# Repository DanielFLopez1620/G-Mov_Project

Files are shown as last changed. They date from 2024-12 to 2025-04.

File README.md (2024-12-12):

# G-Mov Project

G-Mov comes from Guardian of Movement. It is a project that aims to integrates robotics in the care of elderly people by combining ROS 2 and IoT for a dashbaord visualization over a local network. By adding a modular kit composed of a pi camera, a servo and a accelerometer to ROS 2 robots with the objective to track people fall detection by implementing Computer Vision (CV) and also using the movement of the robot.

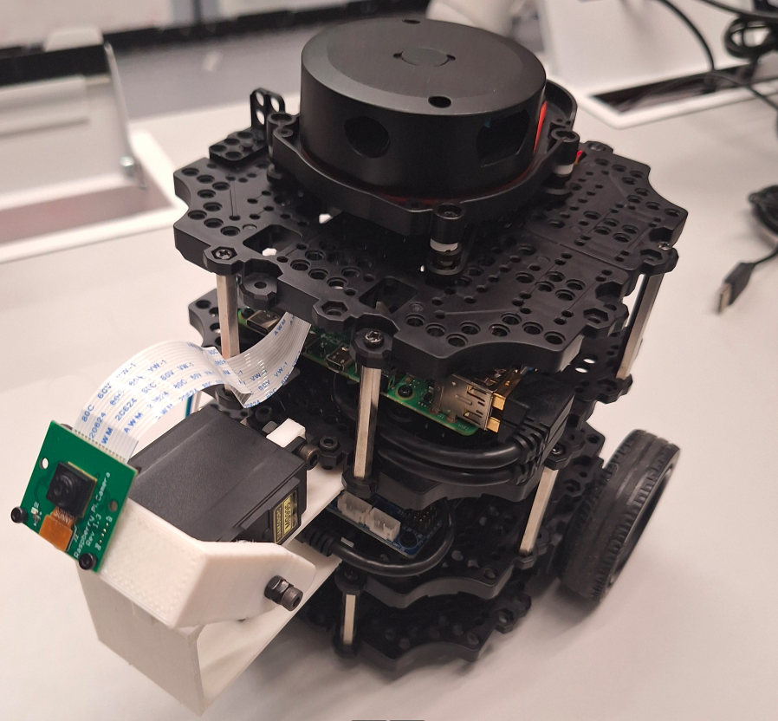
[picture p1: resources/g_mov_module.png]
g_mov_module


For this first version, we have used the [Turtlebot3 Burger](https://emanual.robotis.com/docs/en/platform/turtlebot3/overview/). You can find the demo videos below:

- People tracking:

g_mov_people_tracking

- Fall detection:

g_mov_fall_detection

- Dashboard servo control:

g_mov_servo_control

These videos were recorded at normal speed. If you want to check the original video, you can go to the [G-Mov Phase 3 | Youtube Video](https://youtu.be/IMeLtWwy5p4)

## Technical Information:

This project combines ROS 2 nodes with communication over MQTT by using [Mosquitto](https://mosquitto.org/) and [Thingsboard](https://thingsboard.io/) to generate an interaction between the ROS 2 ecosystem, scripts for CV and communication, a website and a dashboard.

As a note, for now the CV and image processing is made inside the raspberry due to lossy transport of images.

The structure of the project is shown below:

### Packages:

- **[g_mov_base:](/g_mov_base/README.md)** Package with the source code for running the sensors and actuators, and communicating the info over ROS 2 workflow and also with MQTT for Mosquitto, ThingsSpeak and Thingsboard. It also contains the hardware elements and assembly considerations.
- **[g_mov_description:](/g_mov_description/README.md)** Directory that contains the CAD files made in [FreeCad](https://www.freecad.org/) to allow modifications and the .stl files for printing them.
- **[g_mov_cam:](/g_mov_cam/README.md)** Beta package that has experiments for image compression and image transport as it fails and doesn't allow for using the image in another remote ROS 2 system.
- **[g_mov_local_mqtts_notes:](/g_mov_local_mqtts_notes/README.md)** Contains the proper explanation on how to set up Mosquitto broker (base and TLS) and Thingsboard (base installation) for the communication over a local network that must be accesible to the robot and at least another PC.
- **[g_mov_msgs:](/g_mov_msgs/README.md)** Pacakge that contains custom messages, in this case, oriented for the servo pose with a stamped time.
- **[g_mov_opencv_py:](/g_mov_opencv_py/README.md)** Package that incoporates [OpenCV](https://opencv.org/) and [MediaPipe](https://ai.google.dev/edge/mediapipe/solutions/guide) for image processing and CV to detect people fall detection.
- **[g_mov_webpage](/g_mov_webpage/README.md):** Directory that contains the information of the Website that was made with [Flask](https://flask.palletsprojects.com/en/stable/), HTML, CSS and [Bootstrap](https://getbootstrap.com/).

## Limitations:

For now, the project works only with Turtlebot3 and runs with Ubuntu 22.04 for ROS 2 Humble Distro. This was a project made for the IoT Course for the Pontificia Universidad Javeriana, so another limitation was the time to work on the project.

Some additional constraints and limitations to consider are:

- Although it is a IoT project, it just works over a local network as the authors didn't integrate a network host or domain for the webpage due to time limitations.
- The tracking of the person, just works on open spaces where there are not walls where the person could hide and the robot is only able to move in spaces that doesn't have stairs or important height changes. It is possible to detect some parts of the body if the person is behind a partial obstacle but this may affect the tracking.
- Most of the processing is running on the raspberry, so according to the model, it may go slower.

## Future work:

Next semester, according to the develop of the career of the members, have the mission to accomplish one or more of the next items:

* Make a modular design of the kit to allow integration with other robots, for example, [DiffDan](https://github.com/DanielFLopez1620/diff_robot_dan_ros)
* Integrate Docker for easy deployment / installation of the Dashboard and connections.
* Explore integration with SLAM / Nav 2 packages for a more powerful people tracking algorithm in closed spaces.
* Study alternatives for image transport

## About the Authors:

This project was originally made by:

- Daniel Felipe López Escobar : [DanielFLopez1620](https://github.com/DanielFLopez1620)

- Guillermo Aguilera [Best-Gagil](https://github.com/Best-Gagil)

- Cristhian Jose Narvaez. [Criss19](https://github.com/Crisss19)

This project was made by members of the [IEEE RAS Pontificia Unversidad Javeriana Student Chapter](https://linktr.ee/rasjaverianaieee). We would like to thank for the unconditional support and the loan of Turtlebot3 to the directives and members of the Student Chapter.

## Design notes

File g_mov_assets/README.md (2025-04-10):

# g_mov_asssets

In this directory, you can find the cad files and the assembly for the **G-Mov Project** which was made using [FreeCad](https://www.freecad.org/) 1.0.0.

The directory [cad_files](/g_mov_assets/cad_files/) includes all the source files in the .FCStd extension.

The directory [iges_files](/g_mov_assets/iges_files/) includes exported .iges files inc ase you want to make modifications to the project with a different CAD software.

Feel free to modify and generate new versions of this project and share it with us and the community!

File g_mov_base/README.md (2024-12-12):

# g_mov_base

Package oriented to integrate the sensors and actuators of the project into the ROS 2 workflow and enable communication with MQTT for Thingspeak, Thingsboard and Mosquitto.

## Connections and physical set up:

The G-Mov model aims to work with ROS 2 robots that work over a Raspberry Pi 3, 4 or 5 that has the camera port available and allow additional GPIO connections. The elements are:

- **ServoMotor MG996r or MG995:** Actuator that will reorientate the camera for better tracking of the person.

- **MPU6050 Module:** Accelerometer/Gyroscope integration for getting feedback on the robot status.

- **Raspberry Pi Cam:** In this case, the Module V2, which is easy to integrate with the Raspberry Pi and aims for the CV application related with the fall detection tracking system.

The connection for this is presented in the image below (Raspberry Pi 4 case):

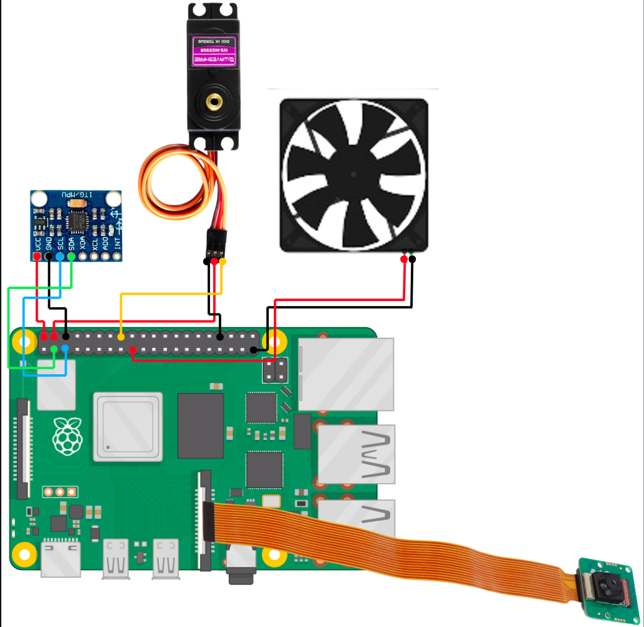
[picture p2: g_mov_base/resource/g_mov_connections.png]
g_mov_connection


In terms of the connection the MPU6050 is connected to the I2C ports of the RPi4, the servo is attached to the GPIO 16 and the cmaera is connected to the proper camera port. All the power connections (5V and GND) are made following the pinout of the RPi (the options presented were added considering ease during installation.) In the case of the Turtlebot3, as it gets power from the RPi 5V port, you can change the MPU6050 to a 3.3 V, move the servo port to the first 5V port and search for another GND to connect the MPU650.

You can 3D print the [g_mov_base_support](/g_mov_description/mesh_files/base_gmov-Body.stl) piece and install all the components there with the appropiate M3 screw for the Turtlebot3 burger model, where you can add the camera in the front or in the back of the robot according to your needs (just keep in mind to change the cmd_vel commands orientation and direction according to the position on the robot, by default, the camara is added at the back of the robot).

## Nodes:

The nodes you can find for this package are presented below:

- **[accel_publisher.py](/g_mov_base/g_mov_base/accel_publisher.py)** : Node that read the I2C connections of the MPU6050, convert it to the provert acceleration and orientation, and publish it to the ROS 2 ecosystem in form of a *AccelStamped* msg.
- **[mosquitto_accel_sub.py](/g_mov_base/g_mov_base/mosquitto_accel_sub.py)** : ROS 2 subscriber that interprates the *AccelStamped* info provided and publish it to the specified Mosquitto broker.
- **[mosquito_fall_sub.py](/g_mov_base/g_mov_base/mosquitto_fall_sub.py)** : ROS 2 subscriber that reads the boolean flag for fall detection and publsih it to the specified Mosquitto broker.
- **[mosquito_servo_sub.py](/g_mov_base/g_mov_base/mosquitto_servo_sub.py)** : ROS 2 subscriber that reads the servo angle and publish it to the specified Mosquitto broker.
- **[servo_subscriber.py](/g_mov_base/g_mov_base/servo_subscriber.py)** : ROS 2 subscriber that folllows the info of a custom *ServoPoseStamped*, interpret it and command the position by using the GPIO ports to the servo.
- **[thingsboatd_accel_sub.py](/g_mov_base/g_mov_base/thingsboard_accel_sub.py)** : ROS 2 subscriber that read the *AccelStamped* info provided and publish it to the specified Thingsboard broker in order to visualize it in a dashboard.
- **[thingsboatd_fall_sub.py](/g_mov_base/g_mov_base/thingsboard_fall_sub.py)** : ROS 2 subscriber that read a boolean flag for fall detection and publish it to the specified Thingsboard broker in order to visualize it in a dashboard.
- **[thingsboatd_servo_sub.py](/g_mov_base/g_mov_base/thingsboard_servo_sub.py)** : ROS 2 subscriber that read the custom *ServoPoseStamped* info provided and publish it to the specified Thingsboard broker in order to visualize it in a dashboard.
- **[thingsboatd_servo_pub.py](/g_mov_base/g_mov_base/thingsboard_servo_sub.py)** : ROS 2 publisher that considers a specified pose in the Thingsboard dashboard and publish the corresponding *ServoPoseStamped* msg.
- **[thingspeak_accel_sub.py](/g_mov_base/g_mov_base/thingspeak_accel_sub.py) : ROS 2 subscriber that aimed to test MQTT connection with Thingspeak from Matlab and explore the usage of this solution during early stages of the project.

## Launch files:

To ease the process of running the sensor and communication nodes, the next launch files were created: 

- **[thingsboard_nodes.launch.py](/g_mov_base/launch/thingsboard_nodes.launch.py)** : Launch file that starts all the Thingsboard nodes for MQTT communication with the dashboard.

- **[sensors_bringup.launch.py](/g_mov_base/launch/sensors_bringup.launch.py)** : Launch files that starts the MPU6050, camera and servo to publish/subscribe in the ROS 2 ecosystem.

- **[mosquitto_nodes.launch.py](/g_mov_base/launch/mosquitto_nodes.launch.py)** : Launch file that initialize the Mosquitto ndoes for MQTT connections with the provided Mosquitto broker.

- **[g_mov_bringup.launch.py](/g_mov_base/launch/g_mov_bringup.launch.py):** Launch files that includes the sensors bringup and thingsboard launch for running the version 1.0 of the *G-Mov Project*.

## Execution:

Currently, the focus on the project is the Thingsboard's Dashboard intregration and the tracking/fall detection module running on the robot.

Before running the robot, make sure the PC hosting the Thingsboard Dashboard and the Thingsboard broker is running. After that you can proceed:

1. Make sure you have cloned the repository:

~~~bash
cd ~/ros2_ws/src
git clone https://github.com/DanielFLopez1620/G-Mov_Project.git
~~~

2. Ensure that all dependenices are available:

~~~bash
pip3 install mpu6050-raspberrypi 
pip3 install rpi-gpio
pip3 install paho-mqtt
pip3 install ssl
pip3 install DateTime
pip install opencv-python
pip install mediapipe
cd ~/ros2_ws
rosdep install --from-paths src --ignore-src --rosdistro humble -y
~~~

3. Ensure that you submitted the proper user/password, hosts and broker credentials before compiling and launching your nodes. This applies for the Mosquitto nodes with the corresponding Mosquitto Broker configuration and the Thingsboard Broker / Database configurations. 

NOTE: If you haven't started your Mosquitto or Thingsboard Services, check [g_mov_local_mqtts_notes](/g_mov_local_mqtts_notes/README.md) for more information.

4. Build the packages

~~~bash
cd ~/ros2_ws
colcon build --packages-select g_mov_msgs g_mov_opencv_py g_mov_base
~~~

5. Run the launch:

~~~bash
source ~/ros2_ws/install/setup.bash
ros2 launch g_mov_base g_mov_bringup.launch.py
~~~

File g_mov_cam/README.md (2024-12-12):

# g_mov_cam

This was a beta repostiroy to test about camera image transport in search for improvements due to heavy lost when using tandard image msgs from ROS 2.

## Nodes:

Here is presented the list of nodes available:

- [custom_image_transport.cpp](/g_mov_cam/src/custom_image_transport.cpp) : Node oriented to explore image transport with the *image_transport* msg by reading the camera with OpenCV.

## Execution:

1. Make sure you have cloned the repository:

~~~bash
cd ~/ros2_ws/src
git clone https://github.com/DanielFLopez1620/G-Mov_Project.git
~~~

2. Connect camera and check permissions, also validate number of device

~~~bash
v4l2-ctl --list-devices

# For example:
# Microsoft® LifeCam HD-3000: Mi (usb-0000:00:14.0-5):
#         /dev/video0
#         /dev/video1
#         /dev/media0
# Where the camera ID should be 0 or 1
~~~

3. Compile and run

~~~bash
cd ~/ros2_ws
colcon build --packages-select g_mov_cam
source ~/ros2_ws/install/setup.bash
ros2 run g_mov_cam custom_image_transport 0 # Or your camera device number
~~~

4. Check image transport

~~~bash
ros2 topic echo /raw_image/compressed
~~~

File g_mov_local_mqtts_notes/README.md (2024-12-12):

# Notes about MQTT with Mosquitto/Thingsboard

This file aims to keep constancy of the steps made when setting up Mosquitto/Thingsboard broker in a local network with or without TLS/SSL for the IoT communication. For additional information refer to the links provided.

## Thingsboard MQTT and Dashboard set up:

For this project, it was used the Thingsboard Community Edition for Ubuntu. The instruction installations are provided in the next link: [Installing Thingsboard CE on Ubuntu Server](https://thingsboard.io/docs/user-guide/install/ubuntu/). However, some modifications were made to the installation:

- PostgresSQL was selected as the ThingsBoard database.

- In the steps were the IP 127.0.0.1 was selected (localhost), it was replaced with the IP of the machine in the local network desired for the application. It was also achieved by adding a custom host to the */etc/hosts* file (Check below in the Mosquitto section for more information), for example in the step:

~~~bash
# psql -U postgres -d postgres -h 127.0.0.1 -W
psql -U postgres -d postgres -h <machine_ip> -W
~~~

- In the thingboard file, the *localhost* was replaced with the machine ip or hostname:

~~~conf
export DATABASE_TS_TYPE=sql
# export SPRING_DATASOURCE_URL=jdbc:postgresql://localhost:5432/thingsboard
export SPRING_DATASOURCE_URL=jdbc:postgresql://<machine_ip>:5432/thingsboard
export SPRING_DATASOURCE_USERNAME=postgres
export SPRING_DATASOURCE_PASSWORD=PUT_YOUR_POSTGRESQL_PASSWORD_HERE
export SQL_POSTGRES_TS_KV_PARTITIONING=MONTHS
~~~

- When asking about the queue service, *In Memory* was selected.

- For checking the installation (after waiting 2 minutes for the restartup) use the machine ip, isntaed of localhost, to connect to the Dashboard online. It should also work with other devices over the network, just make sure that no firewall isn't blocking the connection:

~~~link
http://<maiche_ip>:8080/
~~~

## Thinsboard MQTT with TLS

Although it was implemented at this point of the project, you can find more information on:

- [MQTT over TLS | Thingsboard IO](https://thingsboard.io/docs/user-guide/mqtt-over-ssl/)

## MQTT with TLS on local network with IP setup

After some days of experimentation, reading about Mosquitto Broker, exploring Paho Python Library and having existencial crisis with the keys for TLS by using OpenSSL. I want to include here a brief guide on how to set up the everything in order to have your MQTT broker with TLS for experiments in your local network without having to buy a online service for this if you are not sure if the implementation will work.

### Steps for configuring the keys on your PC

The PC in our case will act as our MQTT broker, for this consider the next steps:

1. Install all the required dependencies

~~~bash
# Mosquito dependencies
sudo apt install mosquitto mosquitto-client

# SSL/TLS dependencies

# Python required
pip3 install paho-mqtt
~~~
https://thingsboard.io/docs/user-guide/install/ubuntu/
2. Create a Certificate Authority Key (CA) key

~~~bash
sudo openssl genpkey -algorithm RSA -out /etc/mosquitto/ca_certicates/ca.key
~~~

3. Create a self-signed CA certificate, make sure to add a **CN** name like "LocalCA" or "test" or related:

~~~bash
sudo openssl req -new -x509 -days 365 -key /etc/mosquitto/ca_certificate/ca.key -out /etc/mosquitto/certs/ca.crt
~~~

4. Create folder for server certificates:

~~~bash
sudo mkdir -p /etc/mosquitto/certs
~~~

5. Generate a server key

~~~bash
sudo openssl genpkey -algorithm RSA -out /etc/mosquitto/certs/server.key
~~~

6. Create a certificate signing request (CSR), make sure to add in the **CN** field the IP adress or hostname or FQDN of your server (your PC). Also do not use the same info for the company or city field, as if they are the same, the verification of the keys can be omitted, which can lead to future errors.

~~~bash
sudo openssl req -new -key /etc/mosquitto/certs/server.key -out /etc/mosquitto/certs/server.csr
~~~

7. Sign the server certificate using the CA certificate:

~~~bash
sudo openssl x509 -req -in /etc/mosquitto/certs/server.csr -CA /etc/mosquitto/ca_certificates/ca.crt -CAkey /etc/mosquitto/ca_certificates/ca.key -CAcreateserial -out /etc/mosquitto/certs/server.crt -days 365
~~~

8. Configure permissions and ownership

~~~bash
sudo chmod 600 /etc/mosquitto/certs/server.key
sudo chmod 644 /etc/mosquitto/certs/server.crt
sudo chmod 644 /etc/mosquitto/certs/ca.crt

sudo chown mosquitto:mosquitto /etc/mosquitto/certs/server.crt

sudo chown mosquitto:mosquitto /etc/mosquitto/certs/server.key

sudo chown mosquitto:mosquitto /etc/mosquitto/ca_certificates/ca.crt
~~~

9. Update mosquitto configuration, open with your editor (by having sudo access) the mosquitto.conf file:

~~~bash
sudo nano /etc/mosquitto/mosquitto.conf
~~~

Then edit it to consider the next:

~~~bash
pid_file /run/mosquitto/mosquitto.pid

# persistence true
# persistence_location /var/lib/mosquitto/

log_type all
log_dest file /var/log/mosquitto/mosquitto.log

# include_dir /etc/mosquitto/conf.d

listener 8883
protocol mqtt

cafile /etc/mosquitto/ca_certificates/ca.crt
keyfile /etc/mosquitto/certs/server.key
certfile /etc/mosquitto/certs/server.crt

tls_version tlsv1.2

# Allow the next only for test, it is recommended to set user and password)
allow_anonymous true
~~~

10. Kill previous instances of mosquitto to prevent issues

~~~bash
sudo systemctl stop mosquitto
sudo killall mosquitto
~~~

11. Restart mosquitto

~~~bash
sudo systemctl start mosquitto
~~~

12. Test that everything is going right, by publishing and subscribing on different terminals

~~~bash
# Terminal 1
mosquitto_sub -h <hostname/ip> -t "test/topic" --cafile /etc/mosquitto/ca_certificates/ca.crt -p 8883
# Terminal 2
mosquitto_pub -h <hostname/ip> -t "test/topic" -m "Hello World" --cafile /etc/mosquitto/ca_certificates/ca.crt -p 8883
~~~

13. You can now run a Python code with Paho to test the publishing and subscribing, in this case if you are running from local, you should set insecure tls to avoid certain validations of paho that may block the connection.

~~~python
import paho.mqtt.client as mqtt
import ssl

broker = "<broker/hostname/ip>"  # Your PC's IP address (broker)
port = 8883  # Port for TLS/SSL

# Define topic
topic = "test/topic"

client_id = "mqtt_pub_client"

ca_cert = "/etc/mosquitto/ca_certificates/ca.crt"  # CA certificate (on Raspberry Pi)

def on_connect(client, userdata, flags, rc, properties):
    if rc == 0:
        print("Connected to broker successfully")
    else:
        print(f"Failed to connect, return code {rc}")

def on_publish(client, userdata, mid, rc, properties):
    print(f"Message published with mid: {mid}")

client = mqtt.Client(mqtt.CallbackAPIVersion.VERSION2, client_id=client_id)

client.tls_set(ca_certs=ca_cert,
               tls_version=ssl.PROTOCOL_TLSv1_2)
client.tls_insecure_set(True)

client.on_connect = on_connectFor Mosquitto issues
client.on_publish = on_publish

client.connect(broker, port)

client.loop_start()

message = "Hello, MQTT with TLS!"
result = client.publish(topic, message)

result.wait_for_publish()

client.loop_stop()
client.disconnect()

print("Disconnected from broker")
~~~

### Additional configurations for user and password

To prevent anonymous connections, you can set up a user and a password, for this you can follow the next steps:

1. Set up the user and password within the proper file with the command below, make sure to remember the password linked to the username

~~~bash
sudo mosquitto_passwd  -c /etc/mosquitto/passwd <username>
~~~

2. Modify your mosquitto.conf file in order to block anonymous connections and ask for user/password by checking a given file:

~~~bash
sudo nano /etc/mosquitto/mosquitto.conf
~~~

~~~bash
allow_anonymous false
password_file /etc/mosquitto/passwd
~~~

3. Test with a publication and a subscription by passing the proper username and password, along with the mosquitto_pub and mosquitto_sub command

~~~bash
# Terminal 1
mosquitto_sub -h 1<hostname/ip> -t "test/topic" --cafile /etc/mosquitto/certs/ca.crt -p 8883 -u <your_username> -P <your_password>

# Terminal 2
mosquitto_pub -h <hostname/ip> -t "test/topic" -m "Hello MQTT over TLS" --cafile /etc/mosquitto/certs/ca.crt -p 8883 -u <your_username> -P <your_password>
~~~

4. In the case you want to test with python, after the mqtt.Client connection, you should set the password and user:

~~~Python
client.username_pw_set("<user>", "<password>")
~~~

### Setting up raspberry pi

1. Make sure you have installed mosquitto on the Raspberry Pi

~~~bash
# Raspberry Terminal
sudo apt install mosquitto mosquitto-clients
~~~

2. You will need to pass the Certificate Authority to the pi, you can use:

~~~bash
# PC terminal
scp /etc/mosquitto/ca_certificates/ca.crt <pi_user>@<pi_ip>:/home/<pi_user>/
~~~

3. Move the **ca.crt** file to the proper location:

~~~bash
# Raspberry terminal
sudo cp ca.crt /etc/mosquitto/ca_certificates/
~~~

4. Test that everything is going OK with **mosquitto_pub** and **mosquitto_sub**

~~~bash
# Terminal 1
mosquitto_sub -h 1<hostname/ip> -t "test/topic" --cafile /etc/mosquitto/certs/ca.crt -p 8883 -u <your_username> -P <your_password>

# Terminal 2
mosquitto_pub -h <hostname/ip> -t "test/topic" -m "Hello MQTT over TLS" --cafile /etc/mosquitto/certs/ca.crt -p 8883 -u <your_username> -P <your_password>

~~~

5. You can now test with Paho in Python, by running the file [localhost_usps_tls.py](/g_mov_local_mqtts_notes/localhost_usps_tls.py)

But you should still need to use the **tls_insecure_set**. That is why we need to configure a hostname that will be covered in the next title.

## MQTT with TLS on local network with hostname setup

### MQTT set up for PC with hostname

1. In your local PC add a new host with the IP of your broker, in this case, your own IP adress.

~~~bash
sudo nano /etc/hosts
~~~

~~~bash
# By default, systemd-resolved or libnss-myhostname will resolve
# localhost and the system hostname if they're not specified here.
127.0.0.1       localhost
::1             localhost

# Add the next host for example, replace x with your IP
192.168.x.x   mqtt.local
~~~

2. Install avahi to resolve the hostname using mDNS:

~~~bash
sudo apt update
sudo apt install avahi-daemon
~~~

3. Enable and start the service

~~~bash
sudo systemctl start avahi-daemon
sudo systemctl enable avahi-daemon
~~~

4. Make sure that the hostname is connected 

~~~bash
ping mqtt.local
~~~

5. After this, you will need to generate new keys, you can generate them with a new name so you can use the previous one, in case you want to have the last configuration as a backup. Follow the next steps to configure the keys again.

6. Create a Certificate Authority Key (CA) key

~~~
sudo openssl genpkey -algorithm RSA -out ca_certificates/ca_host.key
~~~

7. Create a self-signed CA certificate, make sure to add a **CN** name like "LocalCA" or "test" or related:

~~~bash
sudo openssl req -new -x509 -days 365 -key ca_certificates/ca_host.key -out ca_certificates/ca_host.crt
~~~

8. Generate a server key

~~~bash
sudo openssl genpkey -algorithm RSA -out /etc/mosquitto/certs/server_host.key
~~~

9. Create a certificate signing request (CSR), make sure to add in the **CN** field the IP adress or hostname or FQDN of your server (your PC). Also do not use the same info for the company or city field, as if they are the same, the verification of the keys can be omitted, which can lead to future errors.

~~~bash
sudo openssl req -new -key /etc/mosquitto/certs/server_host.key -out /etc/mosquitto/certs/server_host.csr
~~~

10. Sign the server certificate using the CA certificate:

~~~bash
sudo openssl x509 -req -in /etc/mosquitto/certs/server_host.csr -CA /etc/mosquitto/ca_certificates/ca_host.crt -CAkey /etc/mosquitto/ca_certificates/ca_host.key -CAcreateserial -out /etc/mosquitto/certs/server_host.crt -days 365
~~~

11. Edit the mosquitto configuration

~~~bash
sudo nano /etc/mosquitto/mosquitto.conf
~~~

~~~bash
# A full description of the configuration file is at
# /usr/share/doc/mosquitto/examples/mosquitto.conf.example

pid_file /run/mosquitto/mosquitto.pid

log_type all
log_dest file /var/log/mosquitto/mosquitto.log

listener 8883 0.0.0.0
protocol mqtt

cafile /etc/mosquitto/ca_certificates/ca_host.crt
keyfile /etc/mosquitto/certs/server_host.key
certfile /etc/mosquitto/certs/server_host.crt 

tls_version tlsv1.2

allow_anonymous false
require_certificate false

password_file /etc/mosquitto/passwd
~~~

12. Restart mosquito services

~~~
sudo systemctl restart mosquitto
~~~

### MQTT set up for raspberry with hostname

1. In your local PC add a new host with the IP of your broker, in this case, your own IP adress.

~~~bash
sudo nano /etc/hosts
~~~

~~~bash
# By default, systemd-resolved or libnss-myhostname will resolve
# localhost and the system hostname if they're not specified here.
127.0.0.1       localhost
::1             localhost

# Add the next host for example, replace x with your IP
192.168.x.x   mqtt.local
~~~

2. Install avahi to resolve the hostname using DNS:

~~~bash
sudo apt update
sudo apt install avahi-daemon
~~~

3. Enable and start the service

~~~bash
sudo systemctl start avahi-daemon
sudo systemctl enable avahi-daemon
~~~

4. Make sure that the hostname is connected 

~~~bash
ping mqtt.local
~~~

## Troubleshooting:

- Make sure your host IP is unique, for example, if you have others IP set up like for NGrok, ZeroTier, Docker. It is better to disable them to prevent issues. For example, you can use in the case of Docker:

~~~
sudo ip link set docker<id> down
~~~

- If you are not sure about the IP or hostname you set up, it is better to add new keys.

- Remember, do not use the same city, location, company and unit info for CA and server keys, as it will lead to ignore a validation of the keys. Of just one character change, it will be enough

- Keep in mind that Thingsboard service may take 2 minutes to restart if you made some changes to the Thignsboard config or yaml file, this also applies for start up. In case, the startup doesn't apply the proper IP configuration, you should restart postgres and thingsboard services:

~~~bash
sudo systemctl restart postgres # It can also be postgres.service
sudo systemctl restart thingsboard.service
~~~

## Sources and References

- [Mosquitto MQTT Broker SSL Configuration Using Own Certificates | Steves Internet Guide](http://www.steves-internet-guide.com/mosquitto-tls/)

- [Creating and Using Client Certificates with MQTT and Mosquitto | Steves Internet Guide](http://www.steves-internet-guide.com/creating-and-using-client-certificates-with-mqtt-and-mosquitto/)

- [Mosquitto MQTT Broker SSL Configuration Using Own Certificates | Steves Internet Guide](http://www.steves-internet-guide.com/mosquitto-tls/)

- [paho-mqtt 2.1.0 | Pypi.org](https://pypi.org/project/paho-mqtt/#tls-set)

- [Paho Mqtt Python | Github by eclipse](https://github.com/eclipse/paho.mqtt.python)

- [Mosquitto.conf Man Page | Eclipse foundation & Mosquitt.org](https://mosquitto.org/man/mosquitto-conf-5.html)

- [Mosquitto Simple Config Example | Github by timWaizenegger](https://mosquitto.org/man/mosquitto-conf-5.html)

- [Migration Guide for Paho](https://eclipse.dev/paho/files/paho.mqtt.python/html/migrations.html)

- [Mosquitto_sub output format options | AsciiCinema by Raylight](https://asciinema.org/a/82233)

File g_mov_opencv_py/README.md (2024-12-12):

# G_MOV_OPENCV_PY

This package is oriented to integrate pose detection and face recognition in order to create a fall detection program.

The implementations provided here are based on the codes of [fall_detection_DL by barkhaarorra and MahiPajuja @ Github](https://github.com/barkhaaroraa/fall_detection_DL) that where adapted to work on a ROS 2 package and modified in order to run better in a Raspberry Pi 4.

## Installation

### Raspberry PI (Ubuntu 22.04):

Supposing you have python 3.10 (or higher) installed, have a ROS 2 Humble installation and you have cloned this  repository, follow the next steps:

1. Update and upgrade your system:

~~~bash
sudo apt update && sudo apt upgrade
~~~

2. Install Python dependencies and requiered libraries

~~~bash
sudo apt install python3-pip python3-dev libatlas-base-dev libhdf5-dev libjpeg-dev libpng-dev libtiff-dev libjasper-dev libv4l-dev libxvidcore-dev libx264-dev libdc1394-22-dev libgstreamer-plugins-base1.0-dev libgstreamer1.0-dev
~~~

3. Install dlib (required for face_recogniton)

~~~bash
pip3 install dlib
~~~

4. Install computer vision packages

~~~bash
pip3 install opencv-python
pip3 install mediapipe
pip3 install face_recogntion
~~~

5. Run the module example to make sure everythin is fine:

~~~bash
cd /path/to/repo/g_mov_opencv_py/g_mov_opencv_py # Replace with the proper path
python3 modules_demo.py
~~~

### PC (Ubuntu 22.04)

1. Update and upgrade your system:

~~~bash
sudo apt update && sudo apt upgrade
~~~

2. Install computer vision packages

~~~bash
pip3 install opencv-python
pip3 install mediapipe
pip3 install face_recogntion
~~~

3. Run the module example to make sure everythin is fine:

~~~bash
cd /path/to/repo/g_mov_opencv_py/g_mov_opencv_py # Replace with the proper path
python3 modules_demo.py
~~~

## Running the nodes:

1. Do not forget to go to your workspace and build the package

~~~bash
cd /path/to/ros2_ws # Replace with the proper path
colcon build --packages-select g_mov_opencv_py # To build this package only
source install/setup.bash
~~~

2. Run the node:

~~~bash
ros2 run g_mov_opencv_py fall_detect_img_raw_gui.py 
~~~

Refer to [g_mov_base](/g_mov_base/README.md) package in order to check full installation, dependencies and main launch execution.

## Troubleshooting:

- Do not forget to give the proper access to the camera

~~~bash
sudo chmod 666 /dev/video<num_of_camera>
~~~

- Sometimes when downloading multiple computer vision apps, matplotlib can install several times with different version. If you receive warnings related with matplotlib, uninstall and then reinstall it:

~~~bash
pip3 uninstall matplotlib
pip3 install matplotlib
~~~

- Be careful wiht the versions you install of OpenCV and Mediapipe, as they must be compatible. Otherwise, the codes won't work.

## Recommended resources:

- The system has a delay of a little more thant two seconds when running on a Raspeberry Pi 4, then it should be interesting to make tests with OpenCV by using C++ as suggests [StereoPi](https://stereopi.com/blog/opencv-comparing-speed-c-and-python-code-raspberry-pi-stereo-vision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,to%20be%20better%20at%20this) that demostrated it has a better time response for video capture.
- This project uses OpenCV Python, do not forget checking the [documentation](https://docs.opencv.org/3.4/d2/d75/namespacecv.html) if the comments aren't clear.
- This project uses MediaPipe, do not forget checking the [documentation](https://ai.google.dev/edge/mediapipe/solutions/guide) if the comments aren't clear

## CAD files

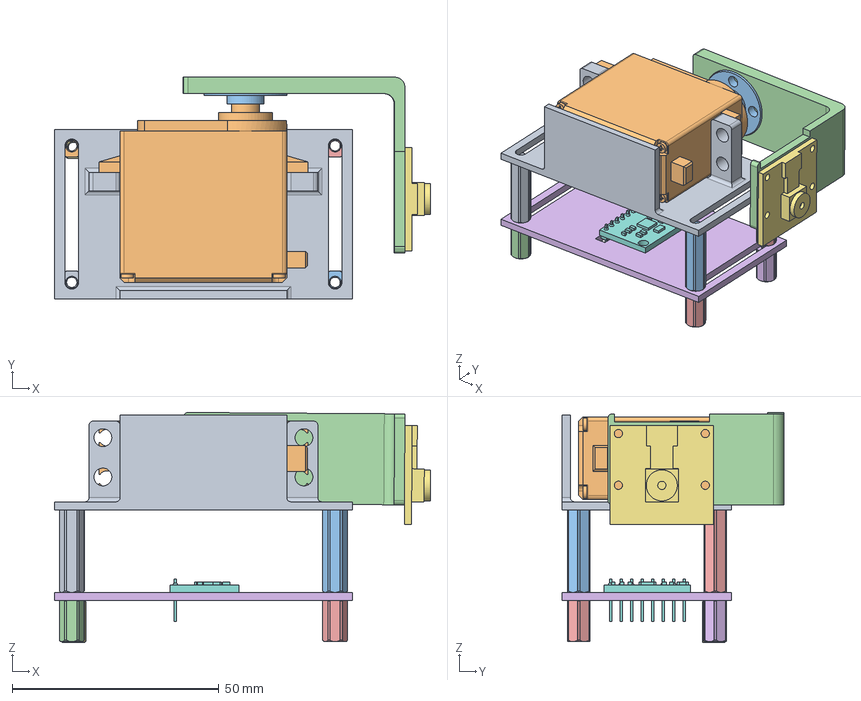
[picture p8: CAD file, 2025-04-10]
g_mov_assets/cad_files/g_mov_assembly.FCStd
90.9 x 53.6 x 55.6 mm
servo_base_001
servo_mg99_001
servo_connection_001
picam_support_001
hex_spacer_20mm_001
acccel_base_001
picam_001
accel_gy_mpu_001
hex_spacer_20mm_002
hex_spacer_20mm_003
hex_spacer_20mm_004
hex_spacer_10mm_001
hex_spacer_10mm_002
hex_spacer_10mm_003
hex_spacer_10mm_004

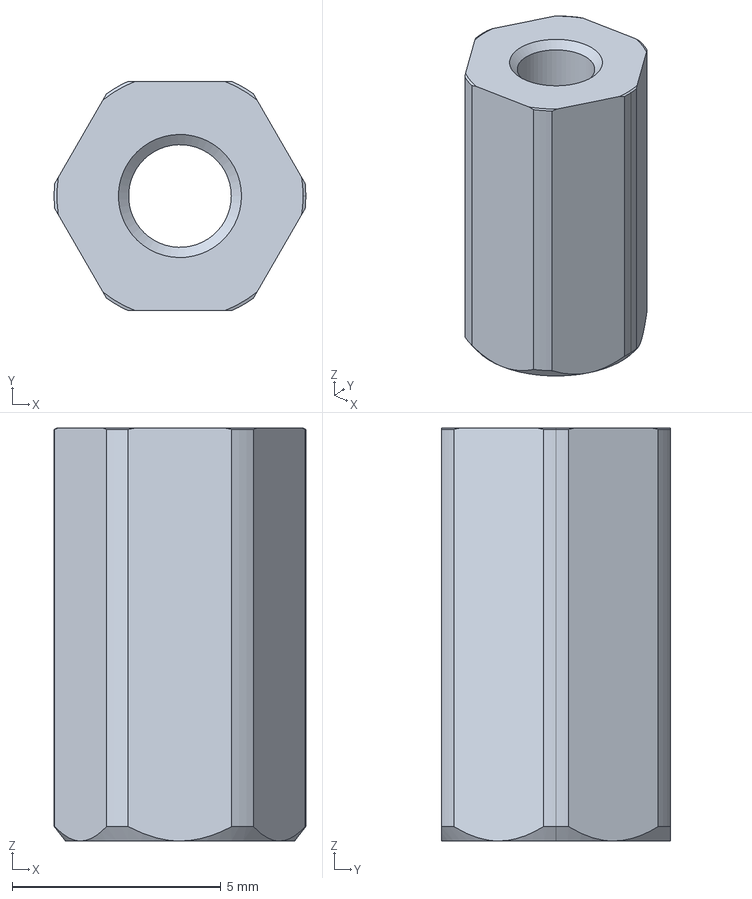
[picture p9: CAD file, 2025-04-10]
g_mov_assets/cad_files/hex_spacer_10mm.FCStd
6.03 x 5.50 x 9.90 mm

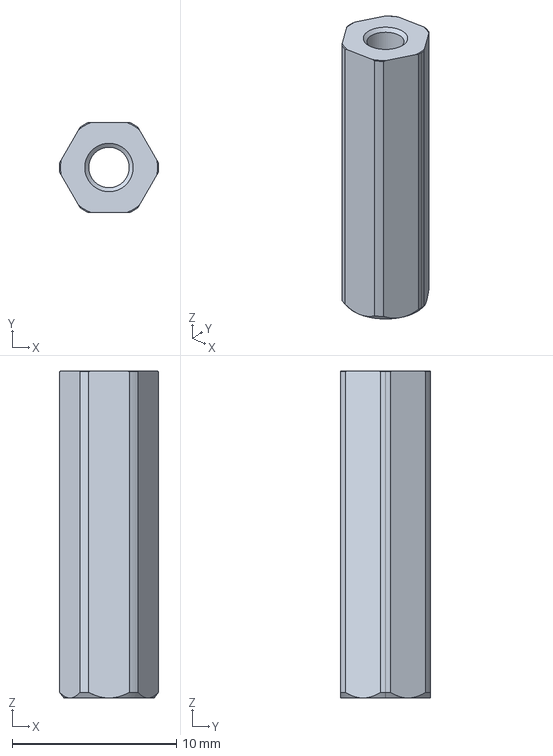
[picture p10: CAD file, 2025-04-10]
g_mov_assets/iges_files/spacer_m3x20.iges
6.03 x 5.50 x 19.9 mm

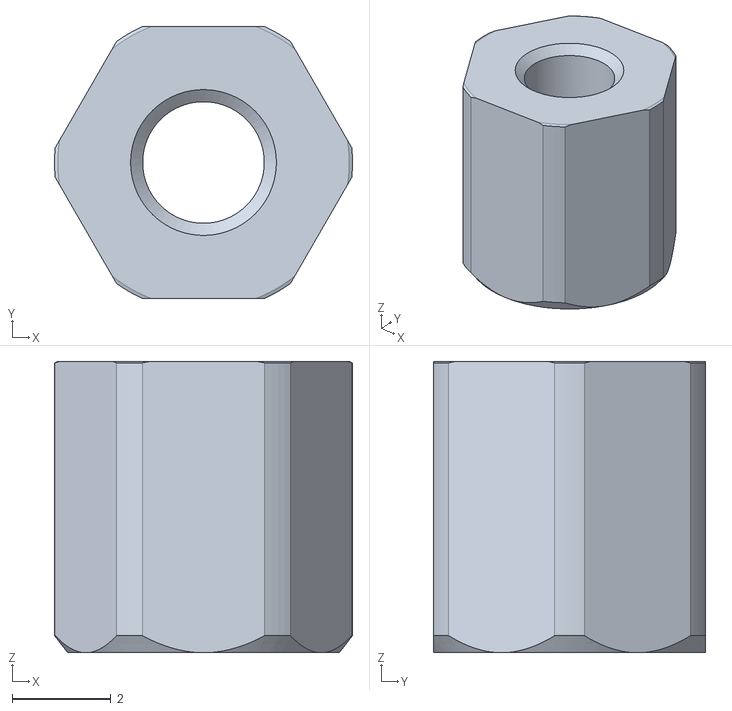
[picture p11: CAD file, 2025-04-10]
g_mov_description/meshes/spacer_m3x6.stl
6.03 x 5.50 x 5.90

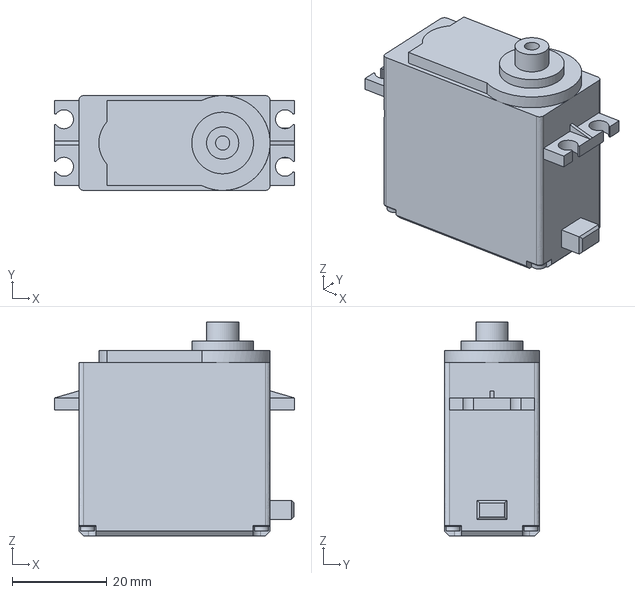
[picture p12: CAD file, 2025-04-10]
g_mov_assets/iges_files/servo_mg996r.iges
50.6 x 20.0 x 45.1 mm

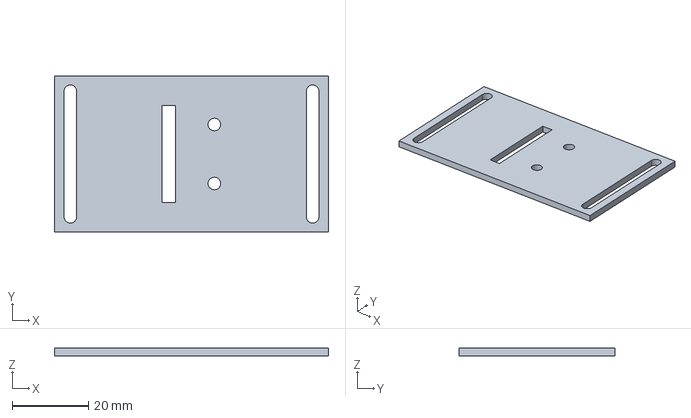
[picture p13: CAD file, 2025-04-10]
g_mov_assets/cad_files/acccel_base.FCStd
72.0 x 41.0 x 2.00 mm

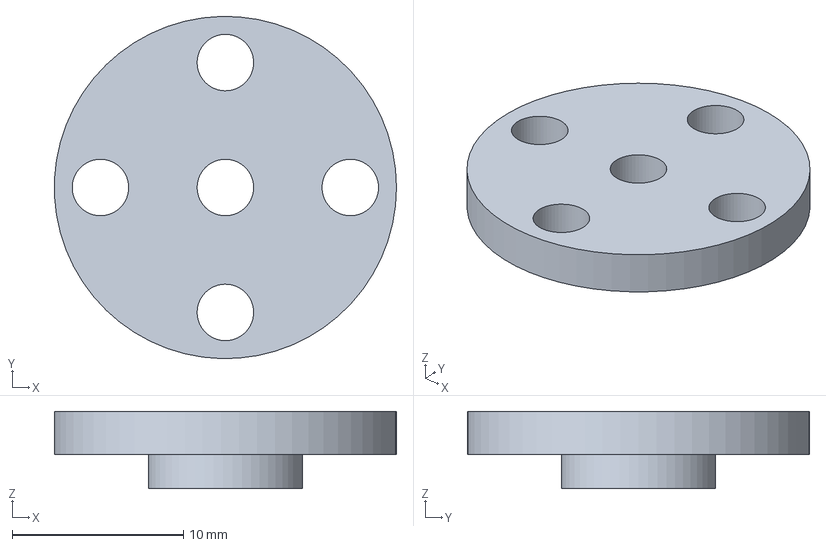
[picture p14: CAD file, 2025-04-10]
g_mov_assets/iges_files/servo_conn.iges
20.0 x 20.0 x 4.50 mm

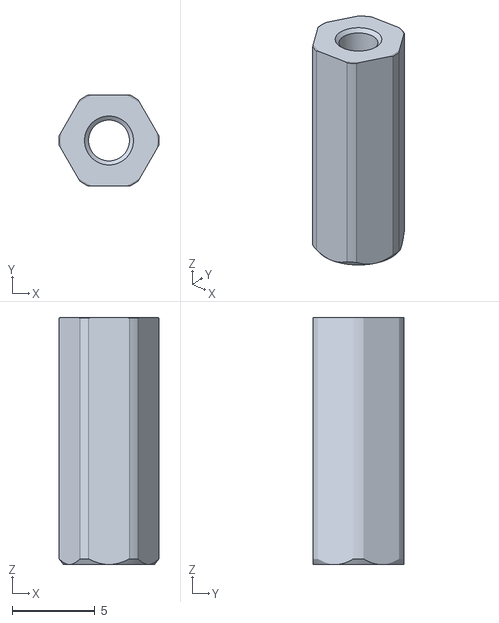
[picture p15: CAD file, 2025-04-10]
g_mov_description/meshes/spacer_m3x15.stl
6.03 x 5.50 x 14.9

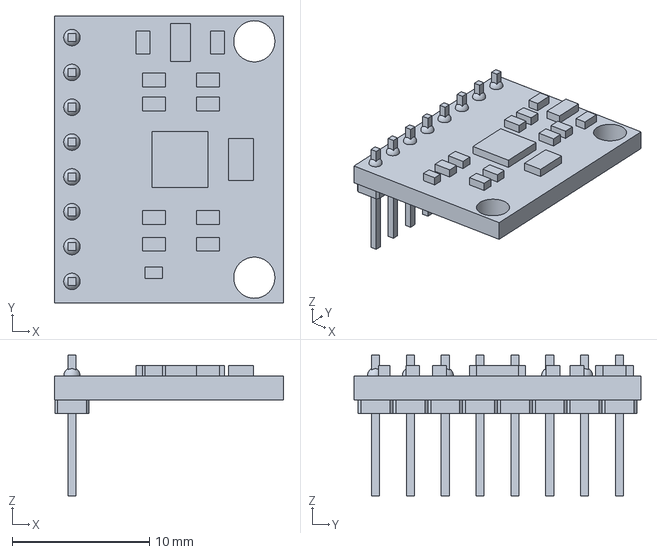
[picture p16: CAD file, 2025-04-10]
g_mov_assets/iges_files/accel.iges
16.7 x 20.9 x 10.2 mm

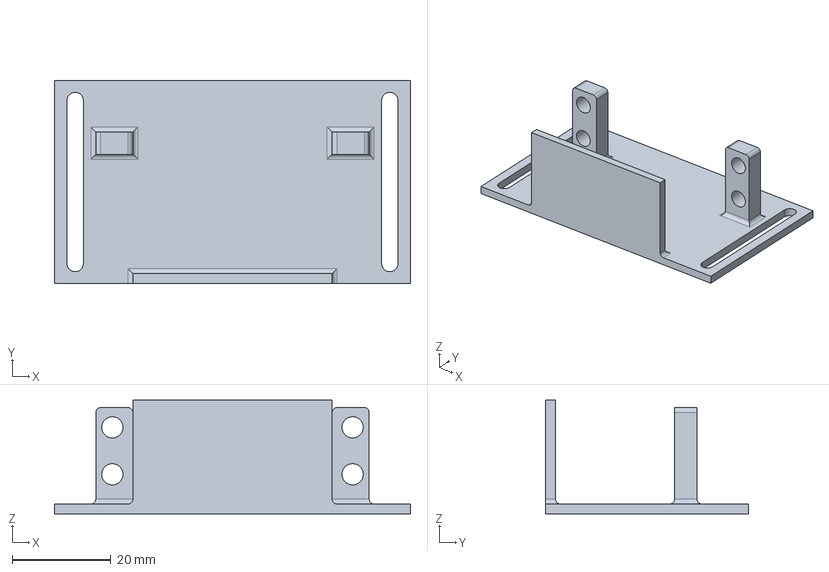
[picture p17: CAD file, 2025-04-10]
g_mov_assets/cad_files/servo_base.FCStd
72.0 x 41.0 x 23.0 mm

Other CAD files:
g_mov_assets/cad_files/hex_spacer_20mm.FCStd
g_mov_description/meshes/servo_mg996r.stl
g_mov_assets/cad_files/hex_spacer_15mm.FCStd
g_mov_description/meshes/spacer_m3x20.stl
g_mov_assets/cad_files/hex_spacer_6mm.FCStd
g_mov_assets/iges_files/spacer_m3x6.iges
g_mov_description/meshes/servo_conn.stl
g_mov_assets/iges_files/spacer_m3x10.iges
g_mov_assets/cad_files/accel_gy_mpu.FCStd
g_mov_assets/cad_files/picam.FCStd
g_mov_assets/cad_files/picam_support.FCStd
g_mov_assets/cad_files/servo_connection.FCStd
g_mov_assets/cad_files/servo_mg99.FCStd
g_mov_assets/iges_files/accel_base.iges
g_mov_assets/iges_files/picam.iges
g_mov_assets/iges_files/picam_support.iges
g_mov_assets/iges_files/servo_base.iges
g_mov_description/meshes/accel.stl
g_mov_description/meshes/accel_base.stl
g_mov_description/meshes/picam.stl
g_mov_description/meshes/picam_sup.stl
g_mov_description/meshes/servo_base.stl
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

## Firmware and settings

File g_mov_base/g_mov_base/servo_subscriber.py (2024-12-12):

#!/usr/bin/env python3
# -*- coding: utf-8 -*-

# ------------------ PYTHON RELATED RASPBERRY PI LIBRARIES --------------------
import RPi.GPIO as GPIO  # General Input/Output Port Management

# ---------------------------- ROS 2 DEPENDENCIES -----------------------------
import rclpy                  # ROS 2 Client Library for Python
from rclpy.node import Node   # Base class for nodes

# -------------------------- ROS 2 REQUIRED MESSAGES --------------------------
from g_mov_msgs.msg import ServoPoseStamped  # Custom servo message

# -------------------------- SERVO ROS2 SUBSCRIBER ----------------------------
class ServoSubscriber(Node):
    """
    Subscriber that receives angular position and set up the servo position by
    using GPIO ports.
    """
    def __init__(self):
        """
        Constructor that initialize the node with the name "servo subscriber",
        create a subscriber linked with a callback to set the servo angle and
        initialize/configure the port and pwm for the servo.
        """
        # Node initialization
        super().__init__('servo_subscriber')

        # Instance subscriber and link callback
        self.subs = self.create_subscription(ServoPoseStamped, 'servo_angle', 
            self.ServoCallback, 10)
        
        # Configure GPIO and PWM
        self.servo_pin = 16
        GPIO.setmode(GPIO.BOARD)
        GPIO.setup(self.servo_pin, GPIO.OUT)
        self.servo_pwm = GPIO.PWM(self.servo_pin, 100)

        # Initialize values
        self.servo_pwm.start(0)
        self.servo_angle = 0
        self.duty = 0

    def __del__(self):
        """
        Destructor that cleanup GPIO port usage and stop the PWM
        """
        self.servo_pwm.stop()
        GPIO.cleanup()

    def AngleToDuty(self, ang) -> float:
        """
        Method that convert from angle to duty cycle for the PWM required to
        set the servo position

        Params
        ----
        ang : float
            Angular position objective

        Return
        ---
        Duty cycle of the given objective
        """
        return float(ang) / 10.0 + 5.0

    def ServoCallback(self, msg) -> None:
        """
        Callback that read the data of the servo position, then process the
        correct PWM to achieve the position and make the proper log.

        Params
        ----
        msg : g_mov_msgs.msg.ServoStamped
            Servo angle msg received
        """
        self.get_logger().info("Servo update received...\nProcessing...")
        
        # Get servo angle value
        self.servo_angle = msg.data

        # Set position
        self.duty = self.AngleToDuty(self.servo_angle)
        self.servo_pwm.ChangeDutyCycle(self.duty)
        
        self.get_logger().info("Servo pose updated: %d" % msg.data)

# -------------------------------- MAIN IMPLEMENTATION ------------------------

def main(args=None):
    """
    Program oriented to subscribe to obtain the servo position and produce it
    by considering GPIO port with the proper PWM.
    """
    # Initialize node
    rclpy.init(args=args)

    # Instance publisher
    servo_subscriber = ServoSubscriber()

    # Manage keyboard exception
    try:
        # Spin node
        rclpy.spin(servo_subscriber)
    except KeyboardInterrupt:
        pass
    finally:
        # Clean and shutdown
        servo_subscriber.destroy_node()
        rclpy.shutdown()

if __name__ == '__main__':
    main()

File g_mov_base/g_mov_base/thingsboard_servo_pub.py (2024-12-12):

#!/usr/bin/env python3
# -*- coding: utf-8 -*-

# -------------------------- PYTHON REQUIRED LIBRARIES ------------------------
import paho.mqtt.client as mqtt   # Library for MQTT connections
import json                       # Json formatting 

# ------------------------- ROS 2 REQUIRED LIBRARIES --------------------------
import rclpy                     # ROS 2 Client Library for Python 
from rclpy.node import Node      # Base class for nodes

# --------------------------- ROS 2 REQUIRED MESSAGES -------------------------
from g_mov_msgs.msg import ServoPoseStamped # Custom servo msg

# --------------------------- GLOBAL VARIABLES --------------------------------
# I know, it is not recommeded but Thingsboard communications got some problems
# and this was the quick fix
servo_value = 0
send_flag = False
sensor_data = {'Servomotor_Angle': 25}

# ------------------ SERVO ROS2 PUBLISHER BASED ON THINGSPEAK VALUE  ----------
class ThingsBoardToServo(Node):
    """
    Class that subscriber to the servo topic controlled in the dashboard in the
    Thingsboard platform, obtain the data and then publish it (by using a 
    ROS 2 publisher) to the servo, in order to change the position.
    """
    def __init__(self):
        """
        Constructor that sets up the communication by using MQTT with paho, to
        connect with the Thingsboard broker as it provides the proper validation
        to the topic with the user and password generated. It also initialize
        the node with the name "thingsboard_to_servo", create the proper publisher
        based on the info received on Thingsboard, with a timer callback for 
        interpreting the values and send them.
        """
        # Initialize node
        super().__init__('thingsboard_to_servo')

        # Instantiate publisher for the servo
        self.publisher = self.create_publisher(ServoPoseStamped, '/servo_angle', 10)

        # Create a timer that validates each two second if there are changes
        self.timer = self.create_timer(2, self.timer_callback)
        
        # MQTT configuration
        self.client = mqtt.Client()
        self.BROKER = 'mqtt.local'
        self.PORT = 1883
        self.ACCESS_TOKEN = '<your_access_token>'
        
        # MQTT callbacks
        self.client.on_connect = self.on_connect  
        self.client.on_message = self.on_message
        
        # Set connection for Thingsboard broker
        self.client.username_pw_set(self.ACCESS_TOKEN)
        self.client.connect(self.BROKER, self.PORT, keepalive=60)

        # Subscribe an make it persistent
        self.client.subscribe('v1/devices/me/rpc/request/+')
        self.client.loop_start()

    def send_velocity(self, grad) -> None:
        """
        Publishes the servo angle by using the custom g_mov_msgs

        Params
        ---
        grad : float
            New servo pose objective
        """
        msg = ServoPoseStamped()
        msg.data = grad
        self.publisher.publish(msg)

    def shutdown(self) -> None:
        """
        Stops MQTT loop and disconnects from the Thingsboard broker
        """
        self.client.loop_stop()
        self.client.disconnect()

    def timer_callback(self) -> None:
        """
        If the flag is true (indicates a change in Thingsboard's dashboard),
        then update the servo position.
        """
        # Use of global variable
        global send_flag, servo_value
        
        # Validation
        if send_flag:
            # Update servo value and add time stamp
            msg = ServoPoseStamped()
            msg.header.stamp = self.get_clock().now().to_msg()
            msg.data = servo_value

            # Publish and reset flag
            self.publisher.publish(msg)
            send_flag = False  

    def on_connect(self, client, userdata, flags, rc):
        """
        On Mqtt connecction, notify and create a log to specify if it was
        succesful or returned an error code. Also, it tries again the
        connection (subscribe)

        Some common errors are timed out (due to connection limits or being in a
        different network) or invalid data (password/certificates)

        Params
        ---
        client : paho.mqtt.client.Client
            Instance client for the callback
        
        userdata : paho.mqtt.client.Client.user_data_set()
            User defined data in client
        
        flags : paho.mqtt.client.ConnectFlags
            Flags according the connection

        rc : paho.mqtt.reasoncodes.ReasonCode
            Codes for identification of errors
        """
        if rc == 0:
            self.get_logger().info("Connected to MQTT broker.")
            client.subscribe('v1/devices/me/rpc/request/+')
        else:
            self.get_logger().error(f"Failed to connect, return code {rc}")

    def on_message(self, client, userdata, msg) -> None:
        """
        If a message is received, process the servo value, also notifies the
        change in thingsboard's dashboard.

        Params
        ---
        client : paho.mqtt.client.Client
            Instance client for the callback
        
        userdata : paho.mqtt.client.Client.user_data_set()
            User defined data in client

        msg : paho.mqtt.client.MQTTMessage
            Message received during connection with the broker
        """
        # Use global variables
        global send_flag, servo_value, sensor_data

        # Check topic
        if msg.topic.startswith('v1/devices/me/rpc/request/'):
            # In case of JSON errors
            try:
                requestId = msg.topic[len('v1/devices/me/rpc/request/'):len(msg.topic)]
                # Decode data in JSon format
                data = json.loads(msg.payload.decode())

                # If it is the set topic... update value and raise flag
                if data.get('method') == 'setValue':
                    params = data.get('params', 0)
                    servo_value = float(params)
                    sensor_data['ServoMotor_Angle'] = params
                    send_flag = True
                    self.get_logger().info(f"Received setValue: {params}")
                # If it is the get value, update with the current pose
                if data['method'] == 'getValue':
                    client.publish('v1/devices/me/rpc/response/' + requestId, 
                        json.dumps(sensor_data['ServoMotor_Angle']), 1)
            except json.JSONDecodeError as e:
                self.get_logger().error(f"Error decoding message: {e}")

        def __del__(self):
            """
            Destruction that will kill connections
            """
            self.shutdown()
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

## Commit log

2024-10-03 Base: Servo subscriber ready
2024-10-03 Base and msgs: Servo subscriber with custom topic and accelerometer publisher ready
2024-10-03 Base: MQTT Publishers to Thingspeak broker that subscribe to ROS2 info
    [accel_publisher.py, servo_subscriber.py, thingspeak_accel_sub.py]
2024-10-03 Web: Simple local straming with camera
2024-10-06 Base: Adding camera subscriber to send raw (text) image to Thingspeak
2024-10-15 MQTTS local: Working form raspberry pi, but still need tls_insecure_set, pending to solve this
2024-10-30 Base: Mosquitto usage with servo and accel
2024-11-13 Base & OpenCV: Fixed multiple mosquitto pub/sub, cam no gui fall detection and general launch
    [mosquitto_fall_sub.py, mosquitto_servo_sub.py, thingsboard_accel_sub.py]
2024-11-14 Base: Added thingsboard nodes (pending test), fixed comments and implement new launch files
    [mosquitto_accel_sub.py, mosquitto_fall_sub.py, mosquitto_servo_sub.py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]
2024-11-18 Base & OpenCV: Fixing camera orientation, merging camera detection with cmd_vel and thingsboard nodes
    [servo_subscriber.py, thingsboard_servo_pub.py]
2024-11-20 Base & OpenCV: Fixing camera detection for movemnt and adding servo publisher
    [thingsboard_servo_pub.py]
2024-12-09 Docs: Adding general and descriptions docs | Description: Adding CAD and stl files
    [assembly_g_mov.FCStd, base_gmov-Body.stl, base_gmov.FCStd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]
2025-02-18 Assets: Migrating assets to start working for the next version
    [assembly_g_mov.FCStd, base_gmov-Body.stl, base_gmov.FCStd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]
2025-02-20 Assets: Designing new assets for servo, cam, accel and platforms
    [acccel_base.FCStd, accel_gy_mpu.FCStd, assembly_g_mov.FCStd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]
2025-02-22 Assets: Refine componentes, added new base cam and mounted assembly
    [acccel_base.FCStd, accel_gy_mpu.FCStd, conexion_servomotor.FCStd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]
2025-02-24 Assets: Finished demo assembly for G-Mov, included additionals spacers sizes
    [acccel_base.FCStd, accel_gy_mpu.FCStd, g_mov_assembly.FCStd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]
2025-02-26 Assets: Reorganizing readme and meshes, which will be later changed
    [base_gmov-Body.stl, conexion_servomotor-Body.stl, mpu6050_accel-Body.stl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]
2025-03-05 Assets: Exported IGES files | Description: Started new description package
    [accel.iges, accel.stl, accel_base.iges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]
2025-03-05 Description: Developed a preeliminary urdf
    [g_mov.urdf.xacro, g_mov_macros.urdf.xacro, g_mov_materials.urdf.xacro]
2025-03-15 Description: Adding camera links and optical links
    [g_mov.urdf.xacro, g_mov_macros.urdf.xacro]
2025-03-16 Description: Adding Gazebo control and camera
    [g_mov.urdf.xacro, g_mov_macros.urdf.xacro]
2025-03-20 Description: Modifying sensors
    [g_mov_macros.urdf.xacro]
2025-03-21 Description: Divide sensors to another xacro file | Gazebo: Added spawn module and basic ros_gz bridge
    [g_mov.urdf.xacro, g_mov_gz.urdf.xacro, g_mov_macros.urdf.xacro]
2025-04-09 Assets: Fixed on screw pockets and added fillets | Description: Updated URDF according new meshes
    [acccel_base.FCStd, accel_base.stl, g_mov.urdf.xacro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]
